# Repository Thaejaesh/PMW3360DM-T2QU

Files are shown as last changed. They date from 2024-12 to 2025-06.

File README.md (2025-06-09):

# FORKED FROM ORIGINAL CREATOR : Good-Great-Grand-Wonderful @ https://github.com/Good-Great-Grand-Wonderful/PMW3360DM-T2QU

# PMW3360DM-T2QU
High-quality pointing for your keyboard projects.

trackball-sensor

## Bill of materials


| Qty | Item | Description |
|-----|---|---|
| 1x  | PMW3360DM-T2QU | Trackball sensor |
| 3x  | 1uF 0402 Capacitor | |
| 1x  | 4.7uF/10V 0402 Capacitor | |
| 1x  | 39ohm 0402 Resistor 0402 | |
| 1x  | 10k 0402 Resistor | |
| 1x  | TLV74318PDBVR | LDO Voltage Regulator |
| 1x  | SM06B-SRSS-TB(LF)(SN) | JST SH 6P Connector |
| 2x  | M3 Brass Inserts | |
| 3x  | 3mmx6mmx2.5mm Ball Bearings | |
| 3x  | 3mmx6mm Allen Set Screws | |
| 2x  | M3x12 Bolts | |
| 1x  | Top carrier | Available in `models` |
| 1x  | Base carrier | Available in `models` |

### Assembly

This board contains small components. While hand soldering is possible, I highly recommend a PCBA service. Gerbers, BOM, and CPL are all available in the Releases section. Choose to assemble the bottom of the PCB, and note that the sensor is intentionally omitted for both cost savings and the convenience of soldering at home.

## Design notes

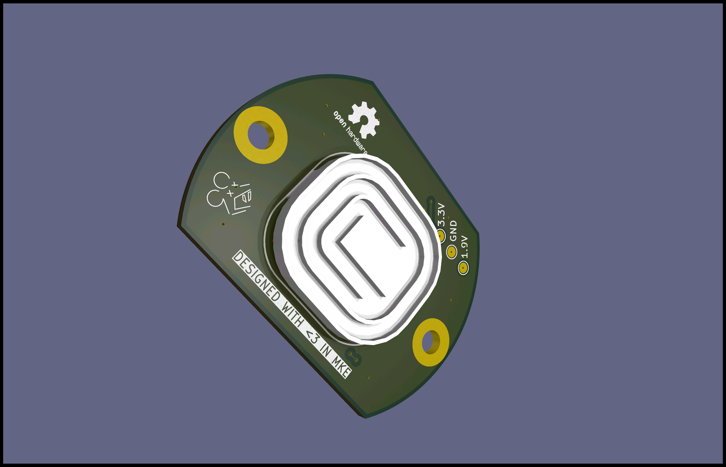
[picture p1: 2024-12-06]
trackball-sensor/trackball-sensor.png

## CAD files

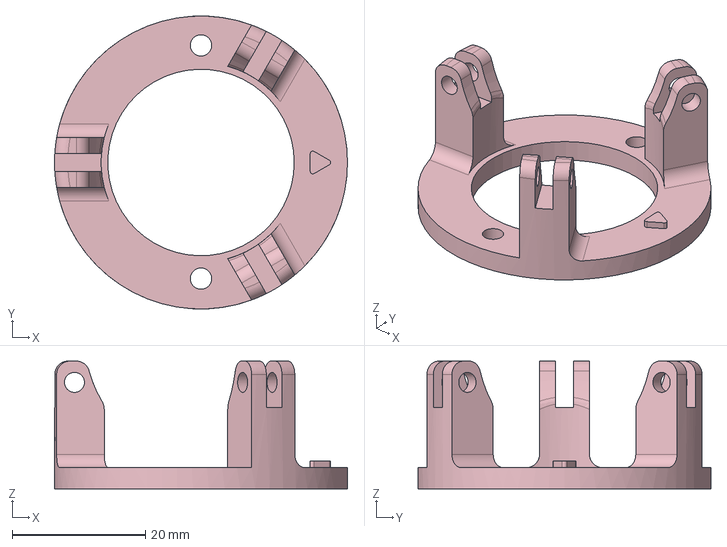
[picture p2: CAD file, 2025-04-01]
models/Trackball Carrier-PartBase.step
44.0 x 44.0 x 19.2 mm

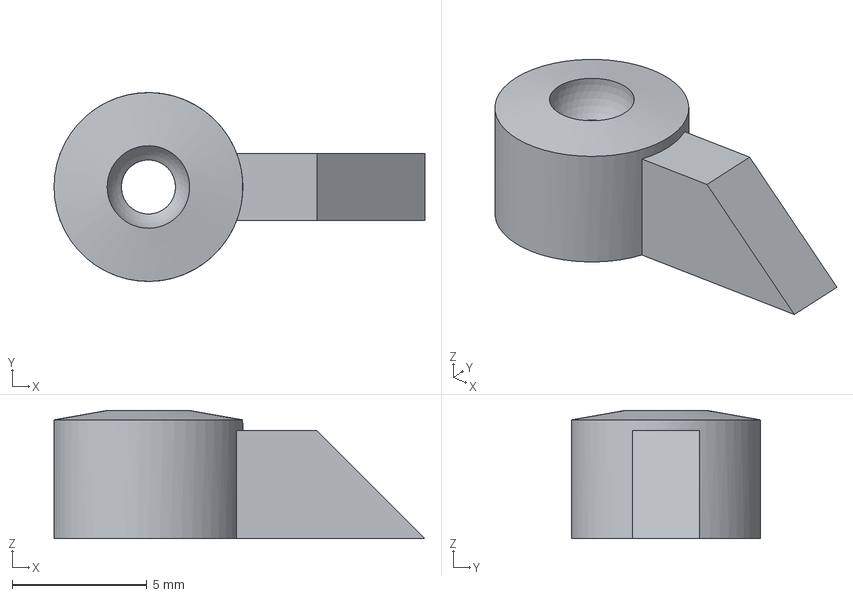
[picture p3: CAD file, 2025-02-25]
models/StaticBearingSlug.step
13.8 x 7.00 x 4.75 mm

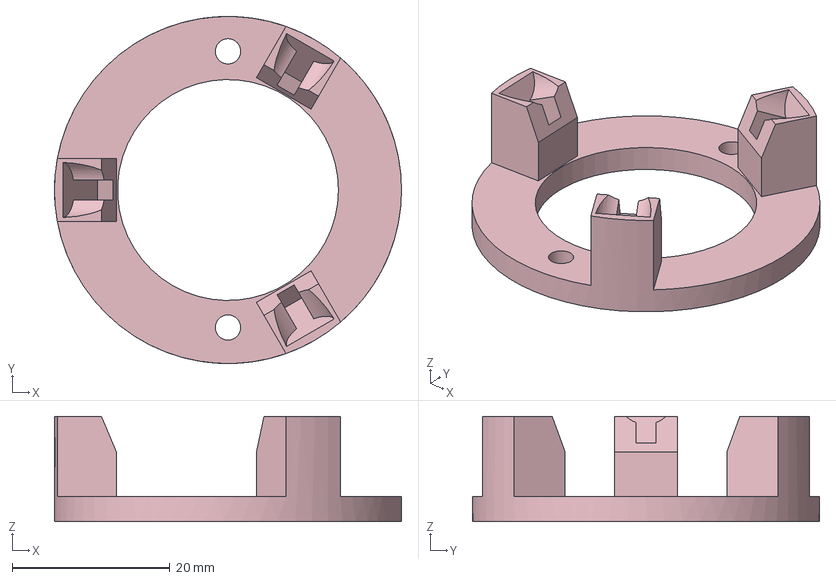
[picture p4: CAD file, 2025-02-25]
models/Trackball Carrier-StaticBearingBase.step
44.0 x 44.0 x 13.3 mm

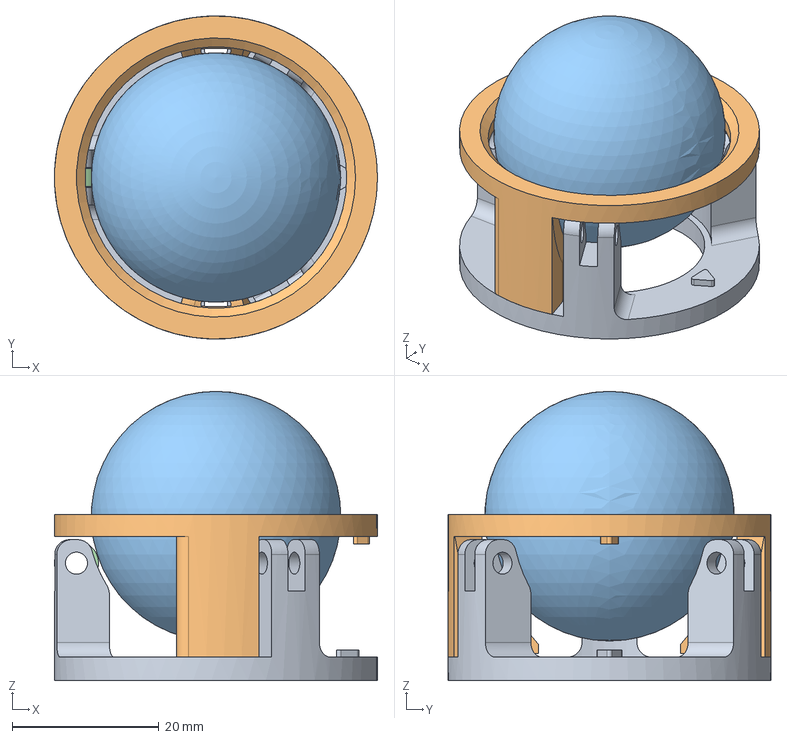
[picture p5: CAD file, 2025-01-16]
models/Trackball Carrier.FCStd
44.0 x 44.0 x 39.4 mm
Base
Top
Trackball
Bearing

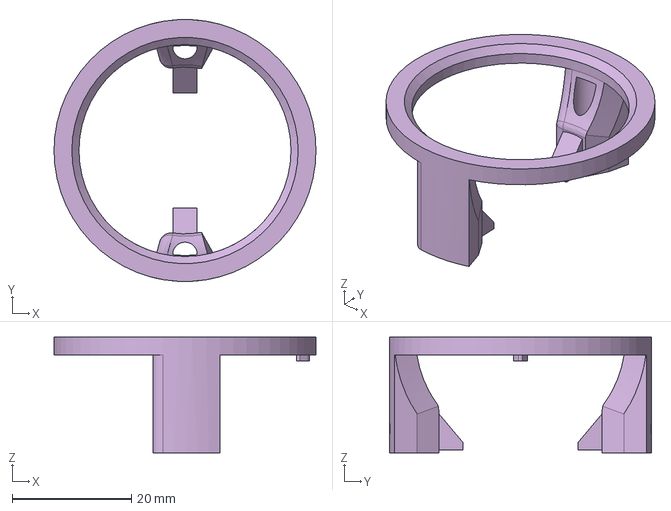
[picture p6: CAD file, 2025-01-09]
models/Trackball Carrier-PartTop.step
44.0 x 44.0 x 19.4 mm

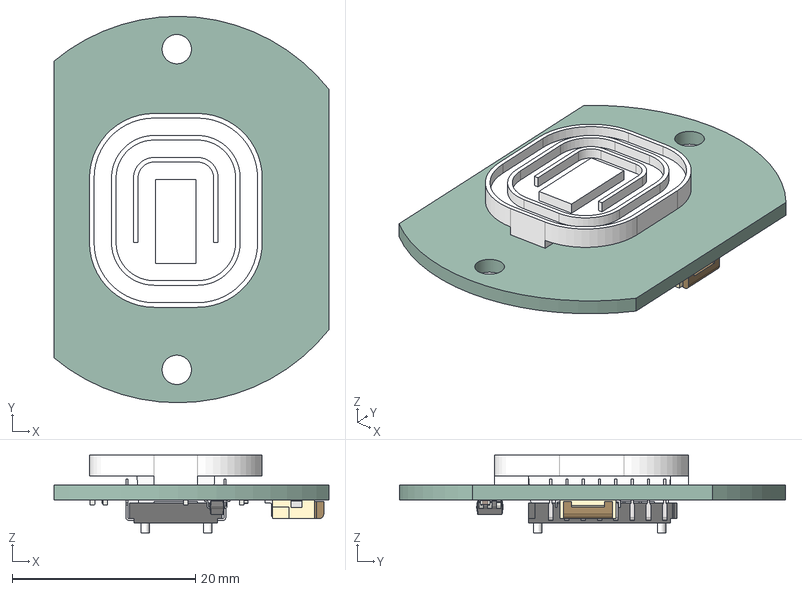
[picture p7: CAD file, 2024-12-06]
models/trackball-sensor.step
30.0 x 42.2 x 8.46 mm
C_0402_1005Metric x 4
SOT_23_5
R_0402_1005Metric x 2
PMW3360 v12
Hirose_FH12_xxS_0_5SH_Parametric_v0_1
trackball-sensor_PCB

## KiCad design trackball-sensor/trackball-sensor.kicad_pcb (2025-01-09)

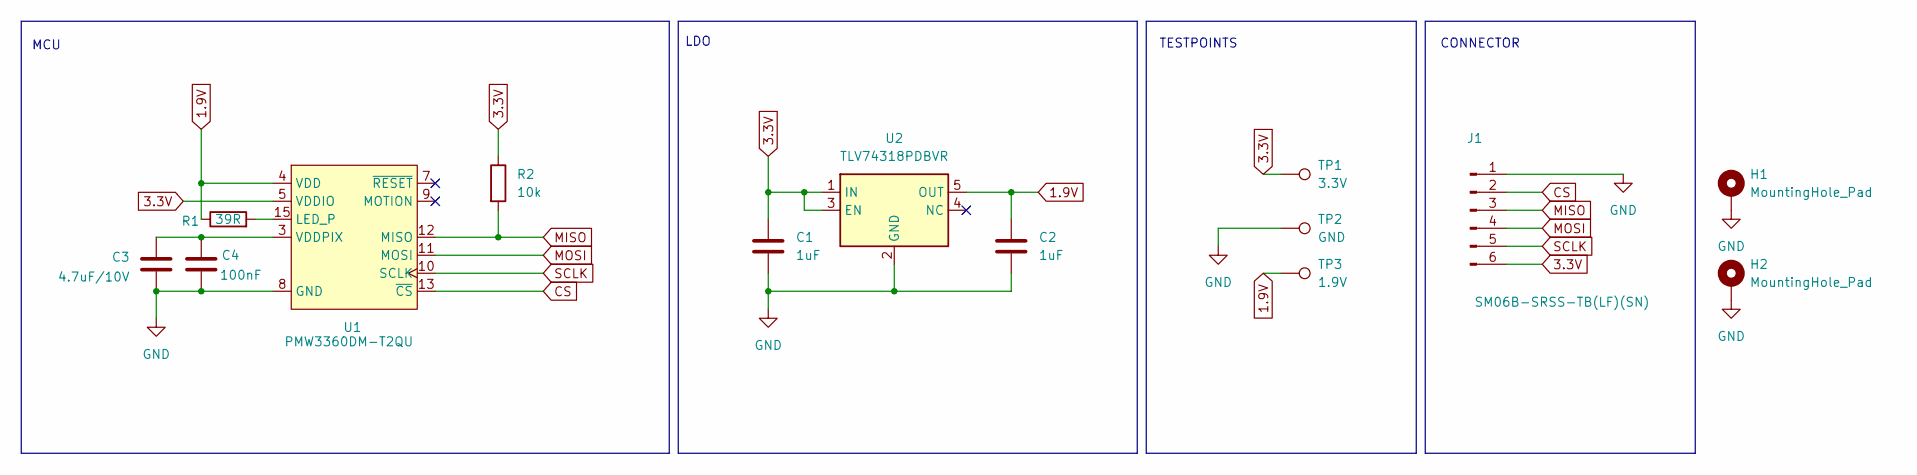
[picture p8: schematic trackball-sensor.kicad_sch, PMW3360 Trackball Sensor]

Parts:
C1, C2: 1uF; C_0402_1005Metric
C3: 4.7uF/10V; C_0402_1005Metric
C4: 100nF; C_0402_1005Metric
H1, H2: MountingHole_Pad; MountingHole_3.2mm_M3_Pad
J1: SM06B-SRSS-TB(LF)(SN)
R1: 39R; R_0402_1005Metric
R2: 10k; R_0402_1005Metric
TP1: 3.3V; TestPoint_Pad_D1.5mm
TP2: GND; TestPoint_Pad_D1.5mm
TP3: 1.9V; TestPoint_Pad_D1.5mm
U1: PMW3360DM-T2QU; PMW3360DM-T2QU 16Pin
U2: TLV74318PDBVR; SOT-23-5

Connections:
1.9V: C2.1, R1.1, TP3.1, U1.4 (VDD), U2.5 (OUT)
3.3V: C1.1, J1.6, R2.1, TP1.1, U1.5 (VDDIO), U2.1 (IN), U2.3 (EN)
CS: J1.2, U1.13 (~CS)
GND: C1.2, C2.2, C3.2, C4.2, H1.1, H2.1, J1.1, TP2.1, U1.8 (GND), U2.2 (GND)
MISO: J1.3, R2.2, U1.12 (MISO)
MOSI: J1.4, U1.11 (MOSI)
unnamed: R1.2, U1.15 (LED_P)
unnamed: C3.1, C4.1, U1.3 (VDDPIX)
SCLK: J1.5, U1.10 (SCLK)

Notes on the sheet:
MCU
LDO
TESTPOINTS
CONNECTOR

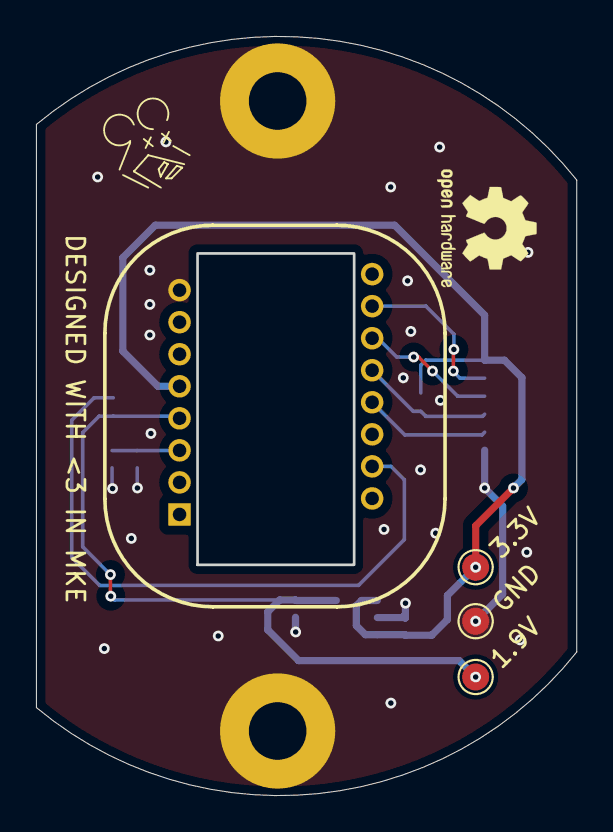
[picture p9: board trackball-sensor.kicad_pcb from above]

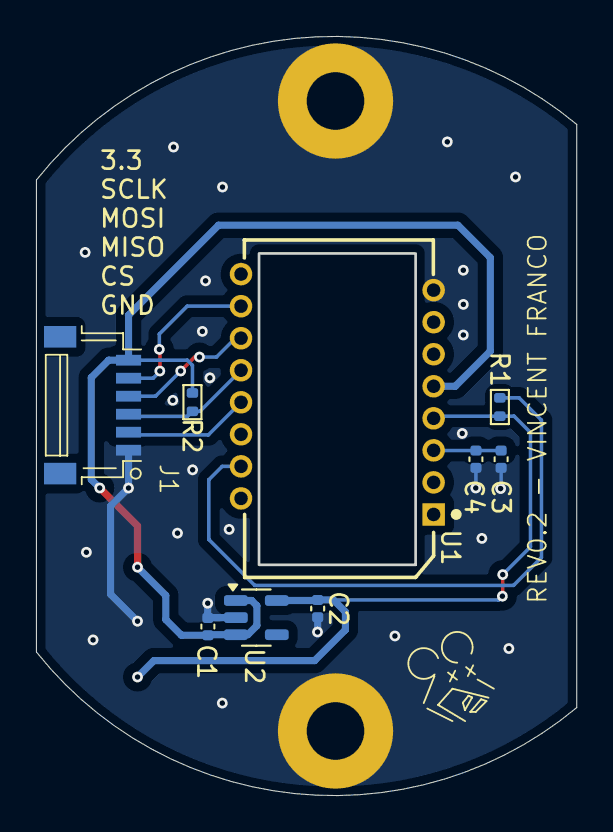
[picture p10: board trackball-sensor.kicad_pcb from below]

Board: 2 copper layers, 30.0 x 42.2 mm, 14 parts (9 on the bottom side), 9 nets.

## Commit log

2024-12-06 Adding KiCad files
    [trackball-sensor.kicad_pcb, trackball-sensor.kicad_sch, trackball-sensor.step]
2024-12-06 Adding models
    [Trackball Carrier-PartBase.3mf, Trackball Carrier-Top.3mf, Trackball Carrier.FCStd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]
2024-12-06 Fixup models
    [Trackball Carrier-PartBase.3mf, Trackball Carrier-PartTop.3mf, Trackball Carrier-Top.3mf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]
2024-12-11 Added license, updating model
    [Trackball Carrier.FCStd, trackball-sensor.step]
2024-12-29 [PATCH] Increasing trackball height by 1mm
    [Trackball Carrier-PartBase.3mf, Trackball Carrier-PartBase.step, Trackball Carrier-PartTop.3mf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]
2025-01-09 Adding indicator to help with assembly
    [Trackball Carrier-PartBase.step, Trackball Carrier-PartTop.step, Trackball Carrier.FCStd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]
2025-01-16 Adjusting roller bearing hole from 3.1mm to 3.0mm
    [Trackball Carrier-PartBase.step, Trackball Carrier.FCStd]
2025-02-25 Adding static bearing models
    [StaticBearingSlug.step, Trackball Carrier-StaticBearingBase.step]
2025-04-01 Updating carrier base
    [Trackball Carrier-PartBase.step]
